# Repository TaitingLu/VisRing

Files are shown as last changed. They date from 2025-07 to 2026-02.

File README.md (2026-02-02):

# VisRing

VisRing is an open-source smart ring platform featuring a curved display and integrated sensing capabilities. This repository contains all necessary files for replicating the hardware, firmware, and enclosure design.

## Repository Structure

- **Case**  
  Contains all 3D printable components of VisRing, including both the outer shell and inner structural case.

- **Firmware**  
  Includes firmware for all core applications such as:
  - Message display
  - Timer
  - Heart rate monitoring

- **PCB**  
  Hardware design files for the VisRing, including schematics, board layout, and bill of materials.

## License

This project is licensed under the **Creative Commons Attribution-NonCommercial-ShareAlike 4.0 International License (CC BY-NC-SA 4.0)**.

You are free to:
- Share — copy and redistribute the material in any medium or format  
- Adapt — remix, transform, and build upon the material  

Under the following terms:
- Attribution — You must give appropriate credit  
- NonCommercial — You may not use the material for commercial purposes  
- ShareAlike — If you remix, transform, or build upon the material, you must distribute your contributions under the same license  

For details, see: https://creativecommons.org/licenses/by-nc-sa/4.0/

## Contact

For questions or collaboration inquiries, please contact txl5518 \at psu.edu.

## Citation

If you use VisRing in your research, please cite our paper:

```bibtex
@inproceedings{lu2025visring,
  title={VisRing: A Display-Extended Smartring for Nano Visualizations},
  author={Lu, Taiting and Krauter, Christian and Liu, Runze and Schulte, Mara and Achberger, Alexander and Blascheck, Tanja and Sedlmair, Michael and Gowda, Mahanth},
  booktitle={Proceedings of the 38th Annual ACM Symposium on User Interface Software and Technology},
  pages={1--18},
  year={2025}
}

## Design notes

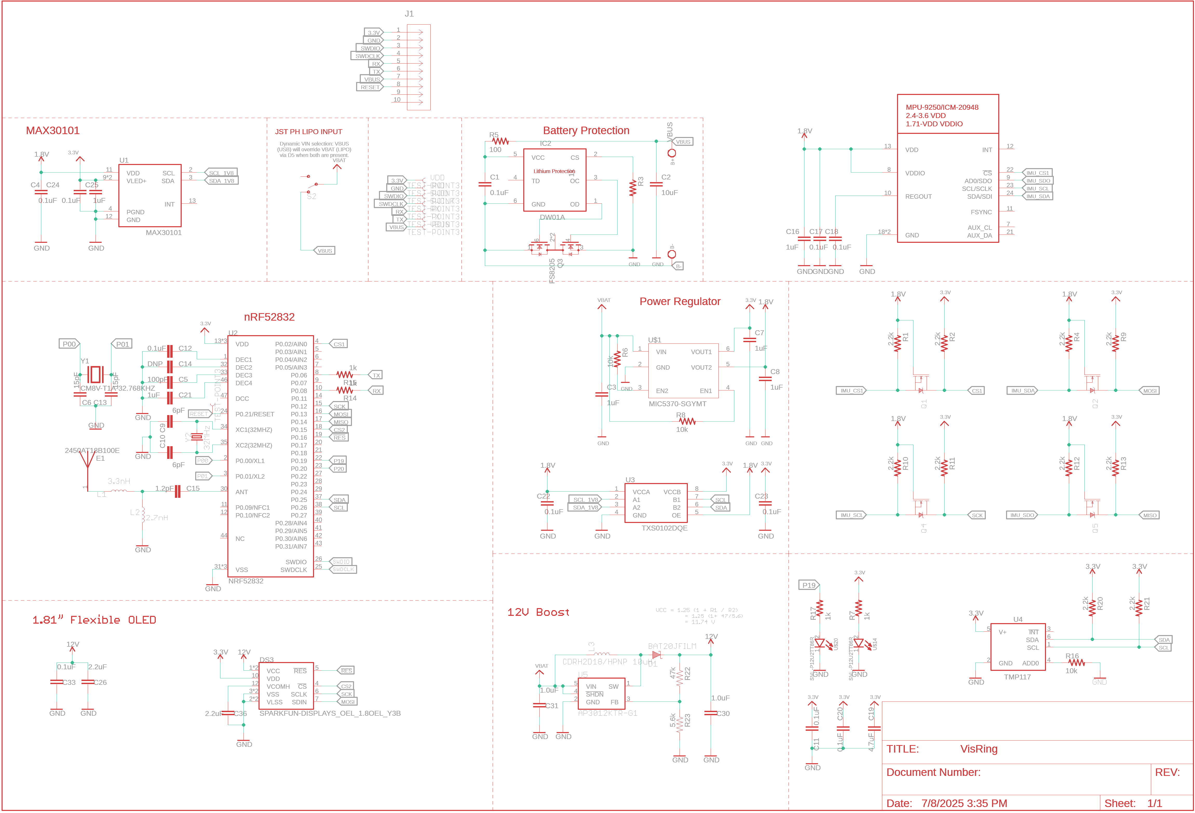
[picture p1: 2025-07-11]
PCB/VisRing_PCB_Schematic.png

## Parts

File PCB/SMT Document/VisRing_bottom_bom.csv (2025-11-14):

Comment | Designator | Footprint | LCSC Part #
0.1uF | C4 C11 C20 C22 C23 C24 | C0201
0.1uF | C33 | SPARKFUN-CAPACITORS_0603
1.0uF | C30 | SPARKFUN-CAPACITORS_0805
1.0uF | C31 | SPARKFUN-CAPACITORS_0603
1k | R14 R15 R17 | R0201
1uF | C25 | C0201
2.2k | R20 R21 | R0201
4.7uF | C19 | C0201
5.6k | R23 | SPARKFUN-RESISTORS_0603
10k | R16 | R0201
47k | R22 | SPARKFUN-RESISTORS_0603
100pF | C5 | C0201
5050701022 | J1 | CONN_505070-1022_MOL
AP3012KTR-G1 | U5 | SOT23-5
BAT20JFILM | D1 | SOD-323
CDRH2D18/HPNP 10uH | L3 | INDUCTOR_4.7UH
DNP | C14 | C0201
MAX30101 | U1 | MAX30100
SML-P12U2TT86R | U$20 | DIODFN100X60X43-2N
TEST-POINT3 | GND RX SWCLK SWIO TX VBUS VBUS1 VDD | PAD.03X.03
TMP117 | U4 | TMP117
TXS0102DQE | U3 | DQE(R-PX2SON-N8)

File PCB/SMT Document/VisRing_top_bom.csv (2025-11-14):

Comment | Designator | Footprint | LCSC Part #
0.1uF | C1 C12 C17 C18 | C0201
1.2pF | C15 | C0201
1k | R3 R7 | R0201
1uF | C3 C7 C8 C16 C21 | C0201
2.2k | R1 R2 R4 R9 R10 R11 R12 R13 | R0201
2.2uF | C26 C36 | SPARKFUN-CAPACITORS_0603
2.7nH | L2 | 0402
3.3nH | L1 | 0402
6pF | C9 C10 | C0201
10k | R6 R8 | R0201
10uF | C2 | C0402
15pF | C6 C13 | C0201
20V/0.2A/8MHz/1.2Ω/1Vth | Q1 Q2 Q4 Q5 | SPARKFUN-DISCRETESEMI_SOT-416FL
32MHz | Y2 | CRYSTAL-SMD-2.0X1.6MM
100 | R5 | R0201
2450AT18B100E | E1 | XDCR_2450AT18B100E
ADAFRUIT_SENSOR_MPU-9250_ICM20948 | IC1 | ADAFRUIT_SENSOR_QFN24_3MM_NOEP
CM8V-T1A-32.768KHZ | Y1 | XTAL_CM8V-T1A-32.768KHZ-7PF-20PPM-TA-QC
DW01A | IC2 | SOT23-6
FS8205 | Q3 | SOT95P280X145-6N
MIC5370-SGYMT | U$1 | SON50P160X160X60-7N
NRF52832 | U2 | QFN48-6X6MM
SML-P12U2TT86R | U$14 | DIODFN100X60X43-2N
SPARKFUN-DISPLAYS_OEL_1.8OEL_Y3B | DS3 | SPARKFUN-DISPLAYS_OEL_1.8_FPC_Y3B

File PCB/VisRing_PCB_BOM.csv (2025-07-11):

Qty | PROD_ID | Names | Value | Package
10 |  | C1; C4; C11; C12; C17; C18; C20; C22; C23; C24 | 0.1uF | C0201
1 |  | C2 | 10uF | C0402
6 |  | C3; C7; C8; C16; C21; C25 | 1uF | C0201
1 |  | C5 | 100pF | C0201
2 |  | C6; C13 | 15pF | C0201
2 |  | C9; C10 | 6pF | C0201
1 |  | C15 | 1.2pF | C0201
1 |  | C19 | 4.7uF | C0201
2 | CAP-00868 | C26; C36 | 2.2uF | C0603
1 | CAP-08064 | C30 | 1.0uF | C0805
1 | CAP-00868 | C31 | 1.0uF | C0603
1 | CAP-00868 | C33 | 0.1uF | C0603
1 | DIO-11623 | D1 | BAT20JFILM | SOD-323
1 | LCD-13910; CONN-13933 | DS3 | SPARKFUN-DISPLAYS_OEL_1.8OEL_Y3B | SPARKFUN-DISPLAYS_OEL_1.8_FPC_Y3B
1 |  | E1 | 2450AT18B100E | XDCR_2450AT18B100E
1 |  | IC1 | ADAFRUIT_SENSOR_MPU-9250_ICM20948 | ADAFRUIT_SENSOR_QFN24_3MM_NOEP
1 |  | IC2 | DW01A | SOT23-6
1 |  | J1 | 5050701022 | CONN_505070-1022_MOL
1 | NDUC-13457 | L1 | 3.3nH | 402
1 | NDUC-13457 | L2 | 2.7nH | 402
1 | NDUC-13968 | L3 | CDRH2D18/HPNP 10uH | INDUCTOR_4.7UH
4 | TRANS_14399 | Q1; Q2; Q4; Q5 | 20V/0.2A/8MHz/1.2?/1Vth | SPARKFUN-DISCRETESEMI_SOT-416FL
1 |  | Q3 | FS8205 | SOT95P280X145-6N
10 |  | R1; R2; R4; R9; R10; R11; R12; R13; R20; R21 | 2.2k | R0201
5 |  | R3; R7; R14; R15; R17 | 1k | R0201
1 |  | R5 | 100 | R0201
3 |  | R6; R8; R16 | 10k | R0201
1 | RES-07871 | R22 | 47k | R0603
1 | RES-12378 | R23 | 5.6k | R0603
1 | SWCH-10651 | S2 |  | SWITCH_SPST_SMD_A
1 |  | U$1 | MIC5370-SGYMT | SON50P160X160X60-7N
2 |  | U$14; U$20 | SML-P12U2TT86R | DIODFN100X60X43-2N
1 |  | U1 | MAX30101 | MAX30100
1 | IC-13460 | U2 | NRF52832 | QFN48-6X6MM
1 |  | U3 | TXS0102DQE | DQE(R-PX2SON-N8)
1 | IC-14700 | U4 | TMP117 | TMP117
1 | VREG-13911 | U5 | AP3012KTR-G1 | SOT23-5
1 |  | Y1 | CM8V-T1A-32.768KHZ | XTAL_CM8V-T1A-32.768KHZ-7PF-20PPM-TA-QC
1 | XTAL-13459 | Y2 | 32MHz | CRYSTAL-SMD-2.0X1.6MM

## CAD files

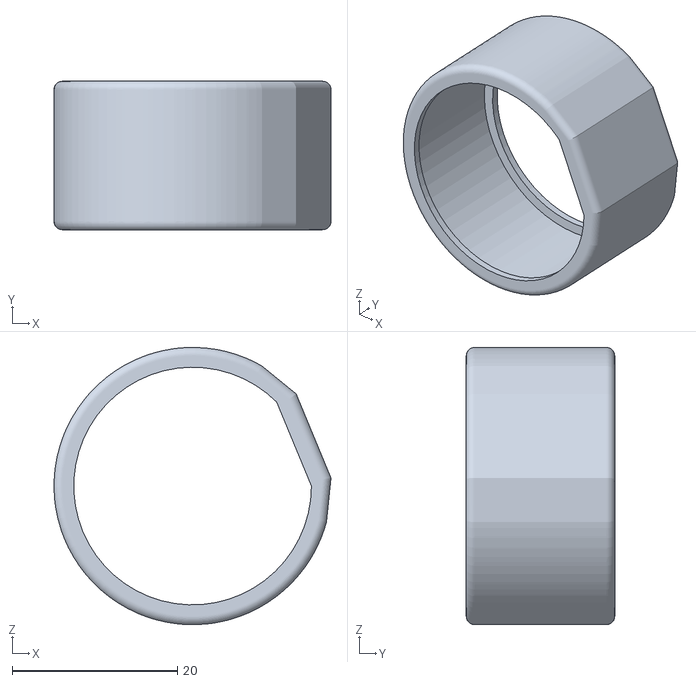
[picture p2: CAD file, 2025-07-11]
Case/outer_case.STL
33.6 x 18.0 x 33.6

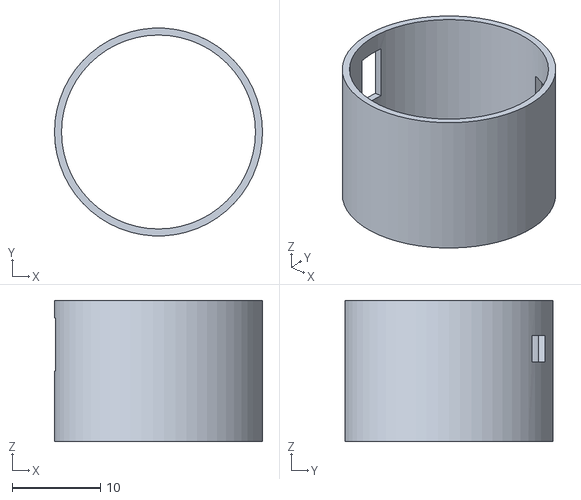
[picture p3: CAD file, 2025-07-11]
Case/inner_case.STL
23.6 x 23.6 x 16.0

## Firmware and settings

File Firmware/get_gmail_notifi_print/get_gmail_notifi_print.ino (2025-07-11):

#include <bluefruit.h>
#include <Wire.h>



uint8_t mode = 0;

String msg;
bool msgflag = 0;
// BLE UART service
BLEUart bleuart;
BLEDis bledis;
BLEDfu bledfu; // DFU Service instance

// === BLE connection callbacks ===
void onConnect(uint16_t connHandle) {
  Serial.println("BLE connected");
}

void onDisconnect(uint16_t connHandle, uint8_t reason) {
  Serial.println("BLE disconnected");
  if (mode == 1){

     Serial.println("Waiting for BLE...");
  }
  // Restart advertising
  Bluefruit.Advertising.start(0);
}

void setup() {
  Wire.begin();
  Serial.begin(115200);
  delay(2000);
  Serial.println("Boot");
  
  // Init BLE
  Bluefruit.begin();
  Bluefruit.setName("VisRing");
  bledis.setModel("VisRing");
  // Set BLE callbacks
  Bluefruit.Periph.setConnectCallback(onConnect);
  Bluefruit.Periph.setDisconnectCallback(onDisconnect);

  // Init BLE UART
  bleuart.begin();
  bledfu.begin();
  bledis.begin();

  // Advertise
  Bluefruit.Advertising.addService(bleuart);
  Bluefruit.Advertising.addService(bledfu);  // DFU advertised
  Bluefruit.ScanResponse.addName();
  Bluefruit.Advertising.start(0);  // 0 = advertise forever
  Serial.println("BLE Started!");
}

void loop() {
  if (bleuart.available()){
      msg = bleuart.readString();
      msg.trim();  // Remove \n or \r if present
      msgflag = 1;
      Serial.print("Received: ");
      Serial.println(msg);
  }
  if (mode == 1){
    Serial.println("mode 1");
  }

}

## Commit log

2025-07-11 update case
    [inner_case.STL, outer_case.STL]
2025-11-14 Update SMT
    [VisRing_bottom_bom.csv, VisRing_top_bom.csv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]
